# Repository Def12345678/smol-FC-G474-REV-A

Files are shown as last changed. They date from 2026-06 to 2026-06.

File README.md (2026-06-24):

# smol-FC

**Work in progress.** This is a Betaflight-based flight controller project, currently in the hardware design phase. 
Everything can change, it's not a final product. 

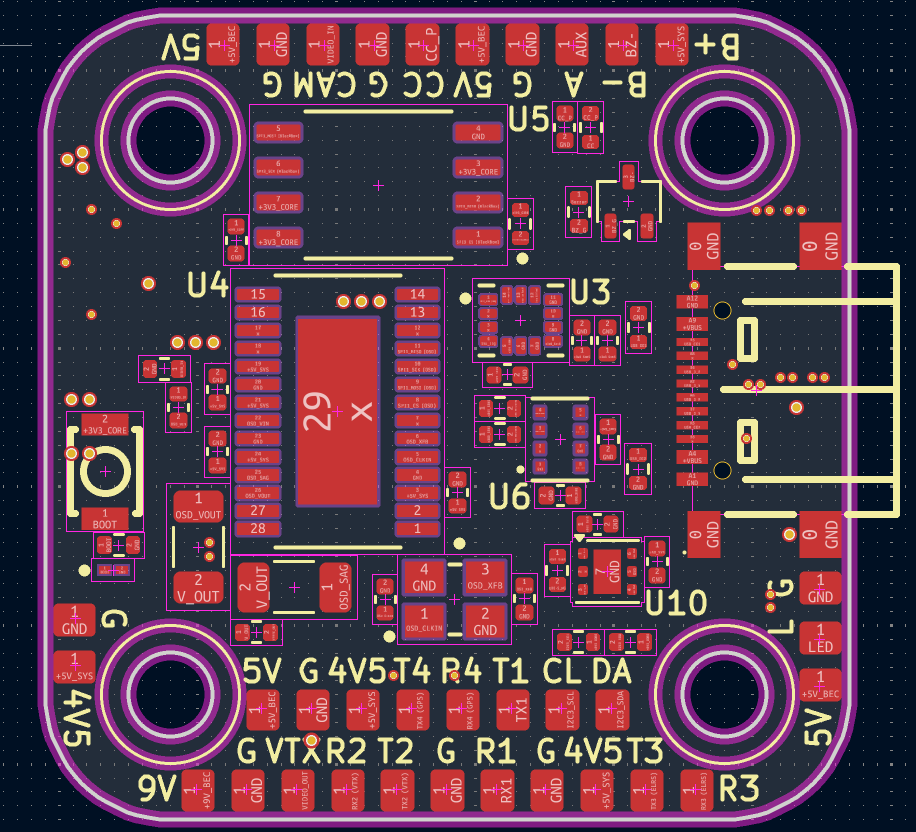
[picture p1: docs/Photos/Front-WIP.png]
Front


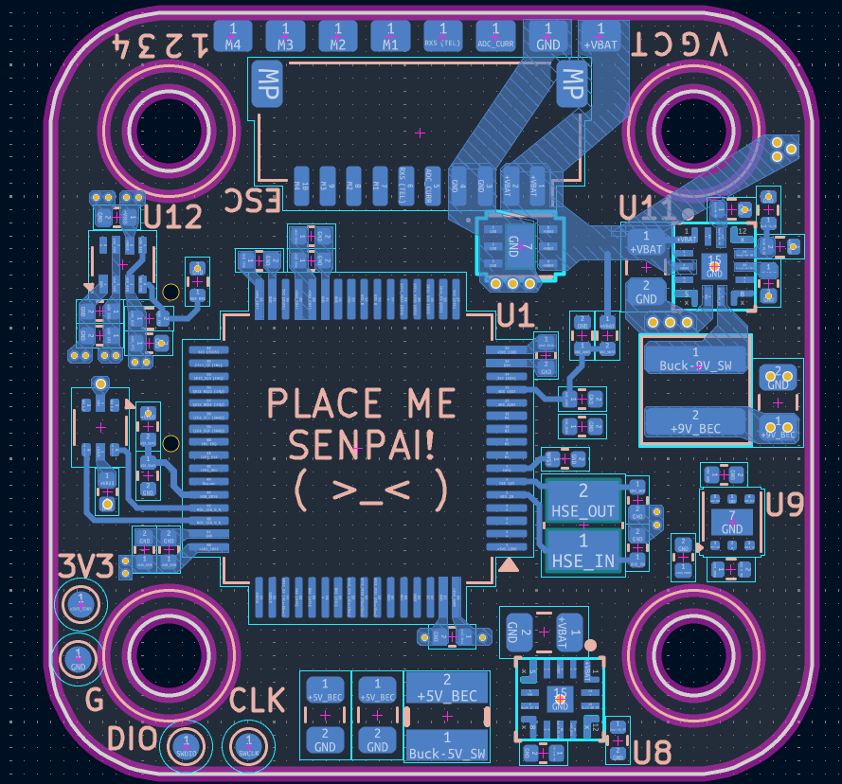
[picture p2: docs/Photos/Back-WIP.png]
Back


## License
This project is licensed under the **CERN Open Hardware Licence v2 - Weakly Reciprocal (CERN-OHL-W-v2)**.

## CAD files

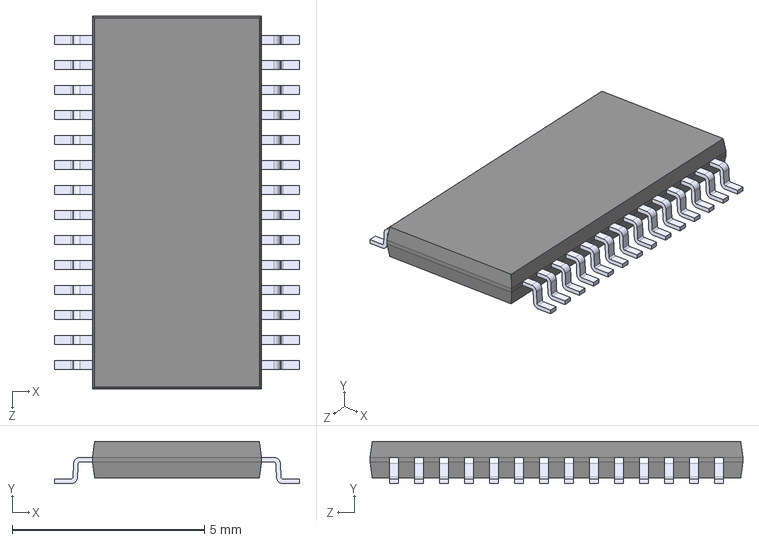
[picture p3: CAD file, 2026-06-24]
smol-FC-G474-REV-A/footprints&symbols/AT7456E/MAX7456EUI_.step
6.38 x 1.10 x 9.70 mm

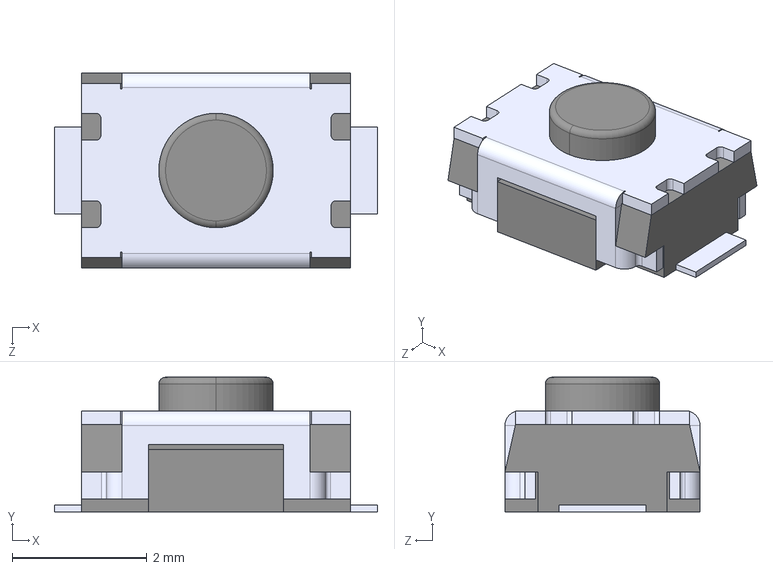
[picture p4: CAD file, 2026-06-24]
smol-FC-G474-REV-A/footprints&symbols/B3U-1000P/B3U-1000P.step
4.80 x 2.00 x 2.90 mm

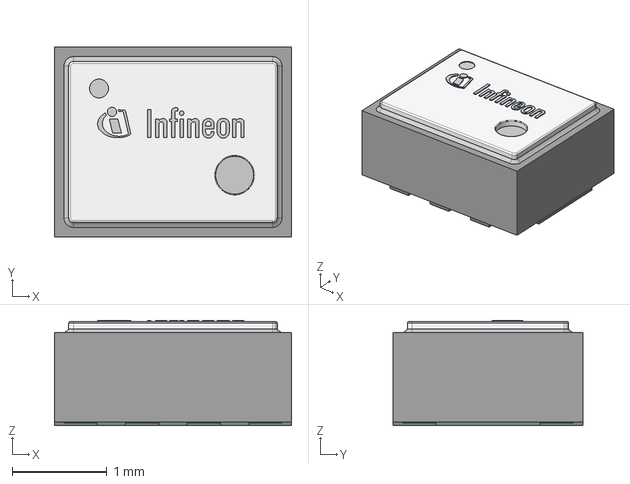
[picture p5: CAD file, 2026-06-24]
smol-FC-G474-REV-A/footprints&symbols/DPS368XTSA1/PG-VLGA-8-2_Z8B00187549_V01_3D.stp
2.50 x 2.00 x 1.11 mm

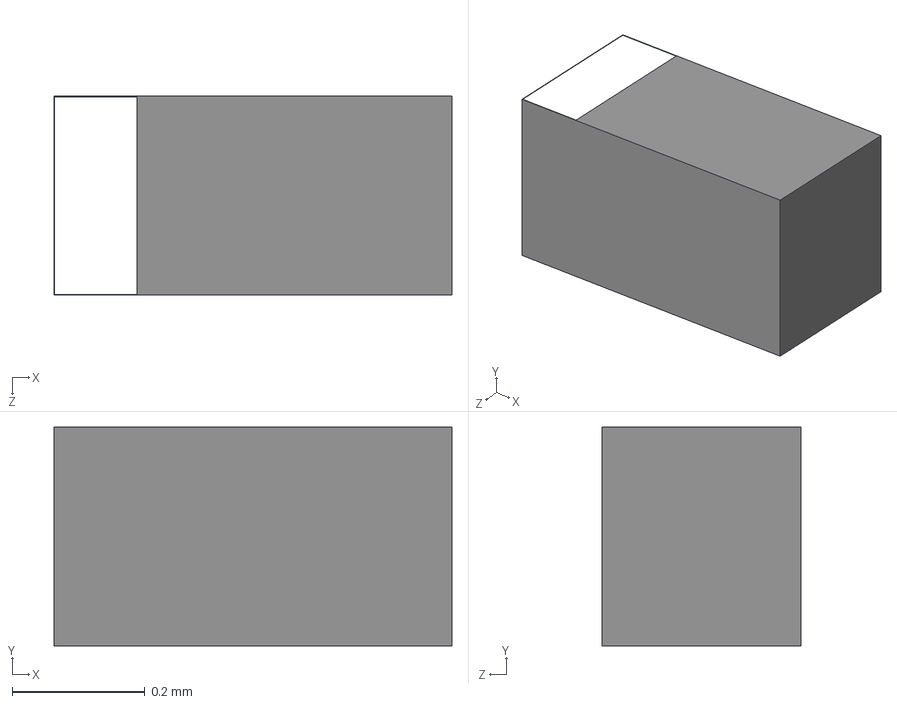
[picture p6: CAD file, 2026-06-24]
smol-FC-G474-REV-A/footprints&symbols/ESDALC6V1-1U2/ESDALC6V1-1U2.step
0.6 x 0.33 x 0.3 mm

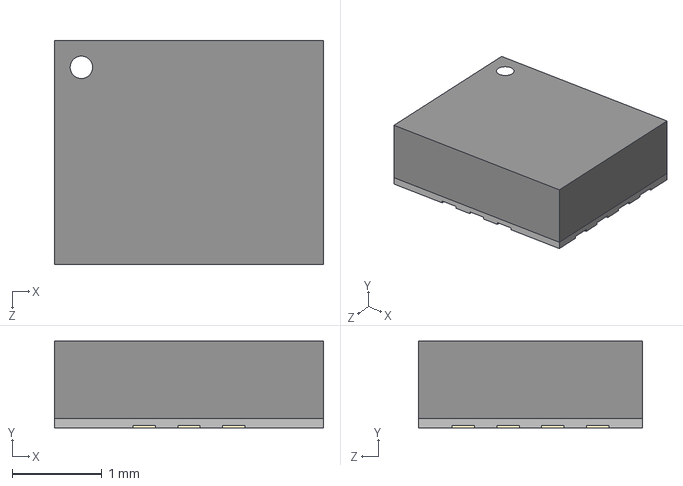
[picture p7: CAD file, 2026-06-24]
smol-FC-G474-REV-A/footprints&symbols/ICM-42688-P/ICM-42688-P.step
3.00 x 0.97 x 2.50 mm

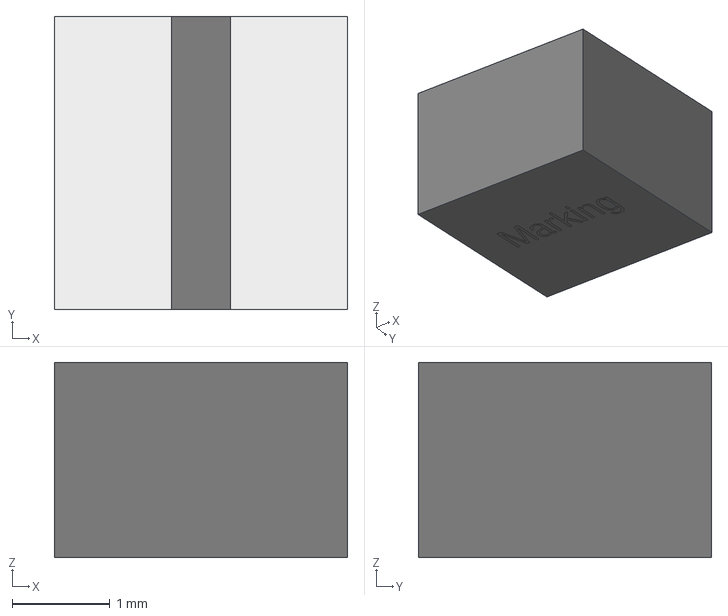
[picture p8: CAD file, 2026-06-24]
smol-FC-G474-REV-A/footprints&symbols/inductor/WE-MAPI_3020+%28rev1%29.stp
3.00 x 3.00 x 2.00 mm

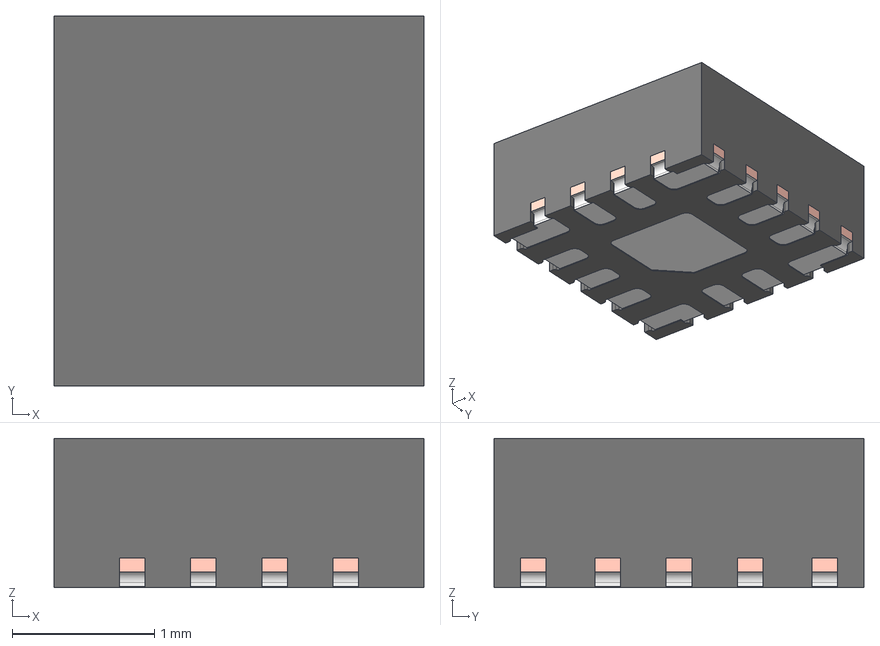
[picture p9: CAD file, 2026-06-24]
smol-FC-G474-REV-A/footprints&symbols/LMQ66430/RXB0014A.stp
2.60 x 2.60 x 1.05 mm
FRAME
PIN1_AREA

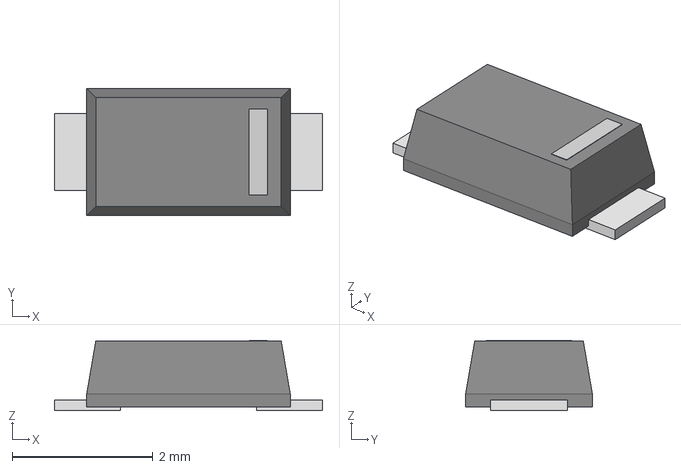
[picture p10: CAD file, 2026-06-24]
smol-FC-G474-REV-A/footprints&symbols/MBR230LSFT1G/CR_0LSFT1G_ONS.step
3.81 x 1.80 x 0.997 mm

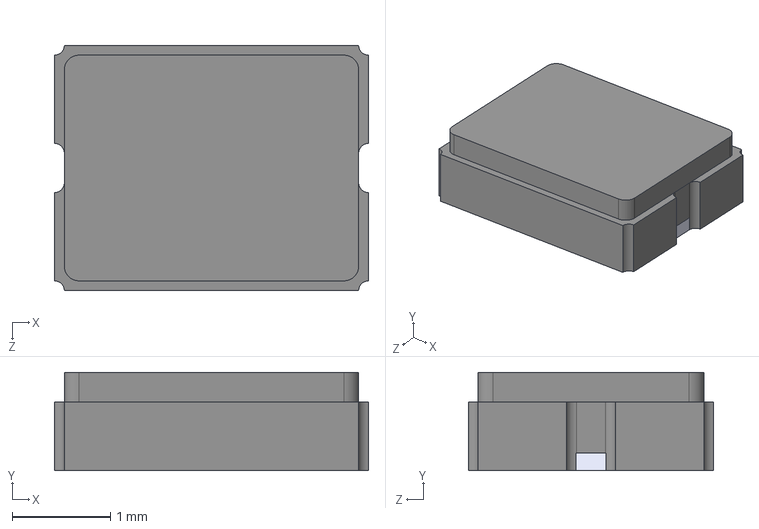
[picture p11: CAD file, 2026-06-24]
smol-FC-G474-REV-A/footprints&symbols/NX3225GD/NX3225GD-8MHZ-STD-CRA-3.step
3.20 x 1.00 x 2.50 mm

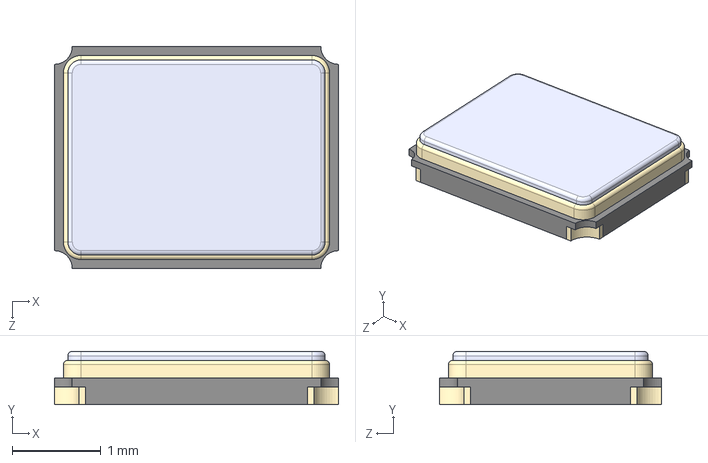
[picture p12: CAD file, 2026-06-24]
smol-FC-G474-REV-A/footprints&symbols/SX1B27.000F0810F30/TSX-3225_16.0000MF18X-AC3.step
3.20 x 0.6 x 2.50 mm

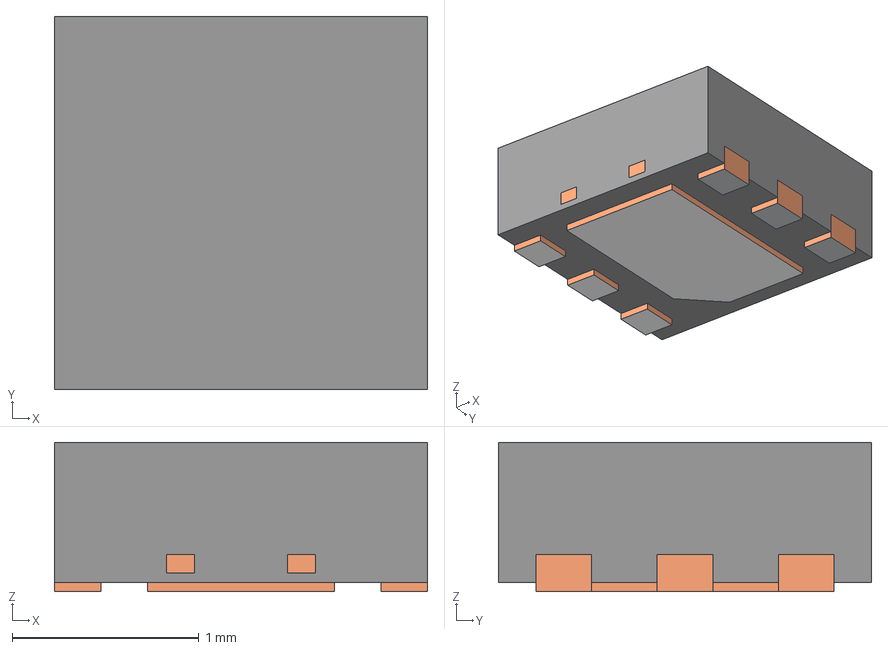
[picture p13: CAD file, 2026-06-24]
smol-FC-G474-REV-A/footprints&symbols/TVS3300DRVR/DRV0006A.stp
2.00 x 2.00 x 0.8 mm
BODY-SON
FRAME-DRV0006A
PIN1-ID

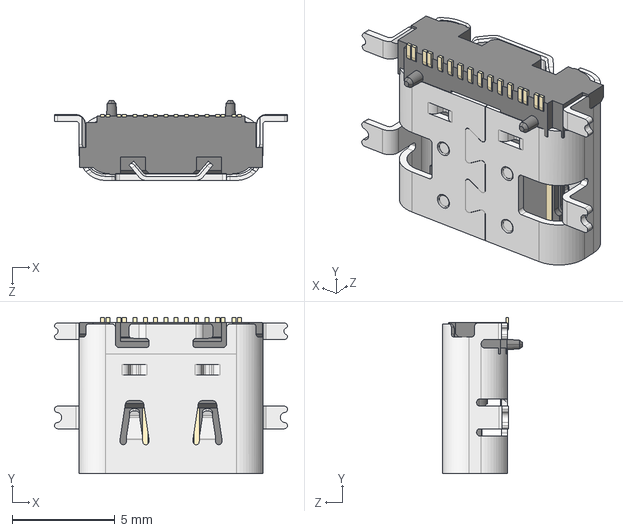
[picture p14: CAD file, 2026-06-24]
smol-FC-G474-REV-A/footprints&symbols/USB-C-SMD/USB-TYPE-C-SMD_TYPE-C-16P-QTWT.step
11.3 x 7.60 x 3.89 mm

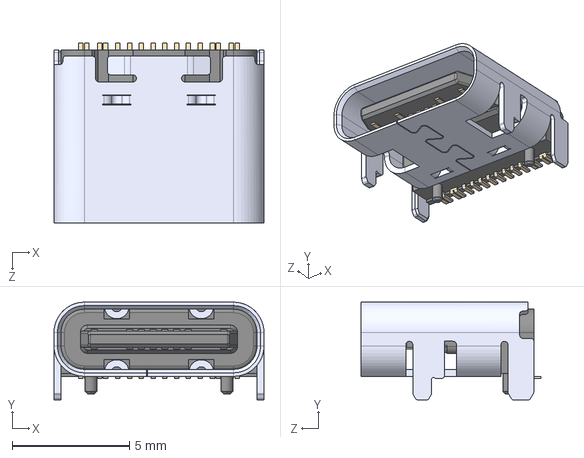
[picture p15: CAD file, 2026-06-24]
smol-FC-G474-REV-A/footprints&symbols/USB-C/TYPE-C_16PIN_2MD__073_.step
8.94 x 4.16 x 7.65 mm

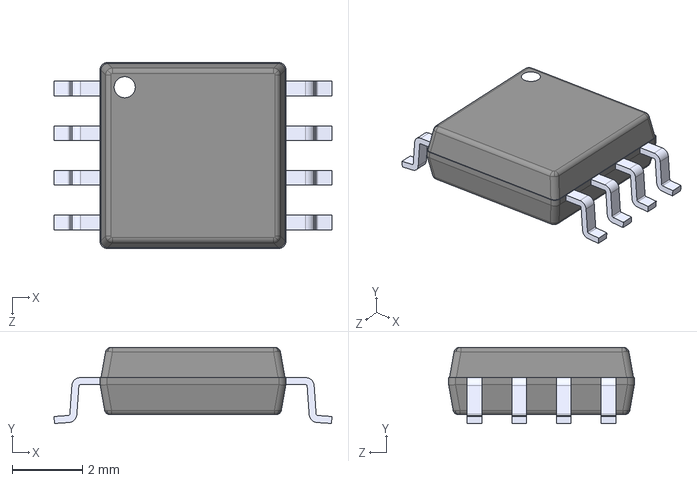
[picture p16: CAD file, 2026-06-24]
smol-FC-G474-REV-A/footprints&symbols/W25Q128JVSIQ/W25Q128JVSIQ.step
7.90 x 2.16 x 5.28 mm

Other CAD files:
freecad/smol-FC-G474-REV-A.FCStd
smol-FC-G474-REV-A/footprints&symbols/B3U-1000P/KEY-SMD_2P-L3.0-W2.5-H1.6-LS4.0.step
smol-FC-G474-REV-A/footprints&symbols/inductor/XAL4030-682MEC--3DModel-STEP-56544.STEP

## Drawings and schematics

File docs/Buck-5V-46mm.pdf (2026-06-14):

## WEBENCH ® Design Report

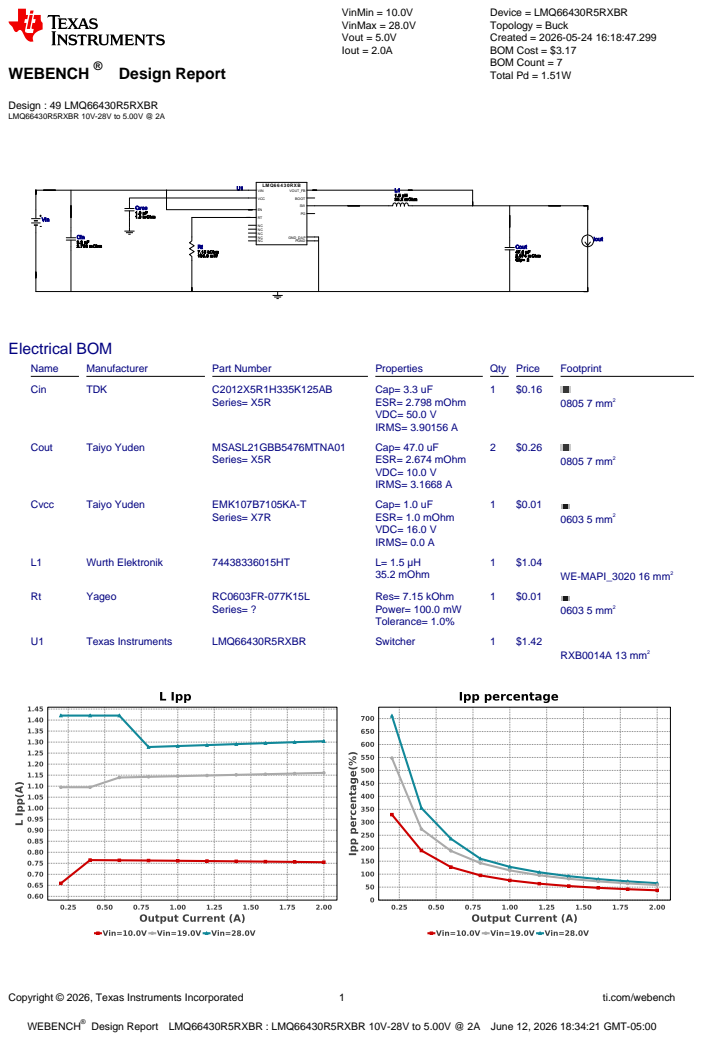
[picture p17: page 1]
Copyright © 2026, Texas Instruments Incorporated; ti.com/webench; WEBENCH®; Design : 49 LMQ66430R5RXBR LMQ66430R5RXBR 10V-28V to 5.00V @ 2A; VinMin = 10.0V VinMax = 28.0V Vout = 5.0V Iout = 2.0A; Device = LMQ66430R5RXBR Topology = Buck Created = 2026-05-24 16:18:47.299 BOM Cost = $3.17 BOM Count = 7 Total Pd = 1.51W; LM Q6 6 4 3 0 RXB; VIN; PGND; BOOT; VCC; VOUT_FB; GND_DAP; Cout 47.0 µF; 2.674 m Ohm Qty= 2; Cin 3.3 µF 2.798 m Ohm; Cvcc 1.0 µF 1.0 m Ohm; L1 1.5 µH 35.2 m Ohm; Rt 7.15 kOhm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

Design Report LMQ66430R5RXBR : LMQ66430R5RXBR 10V-28V to 5.00V @ 2A June 12, 2026 18:34:21 GMT-05:00

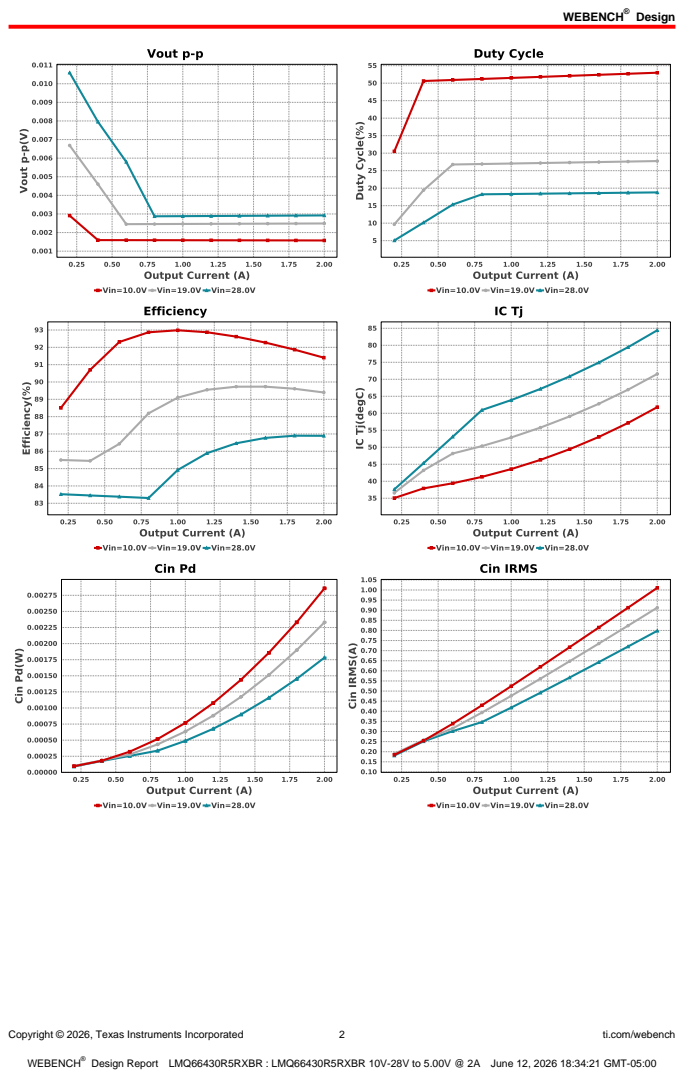
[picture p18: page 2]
Design; Copyright © 2026, Texas Instruments Incorporated; ti.com/webench

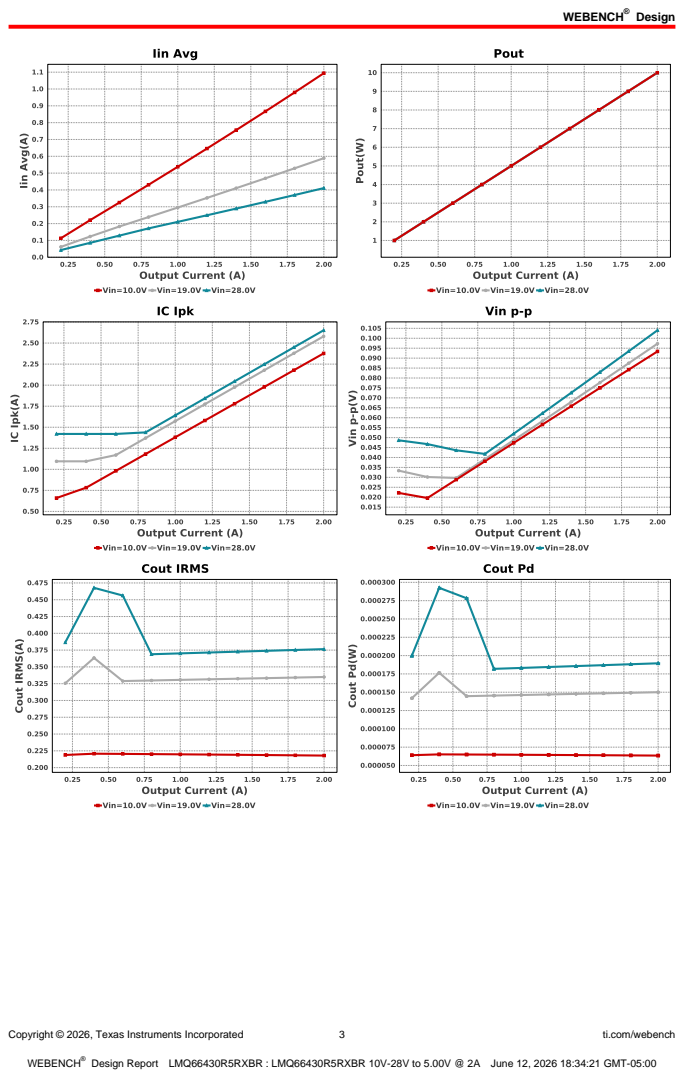
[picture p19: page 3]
Copyright © 2026, Texas Instruments Incorporated; ti.com/webench

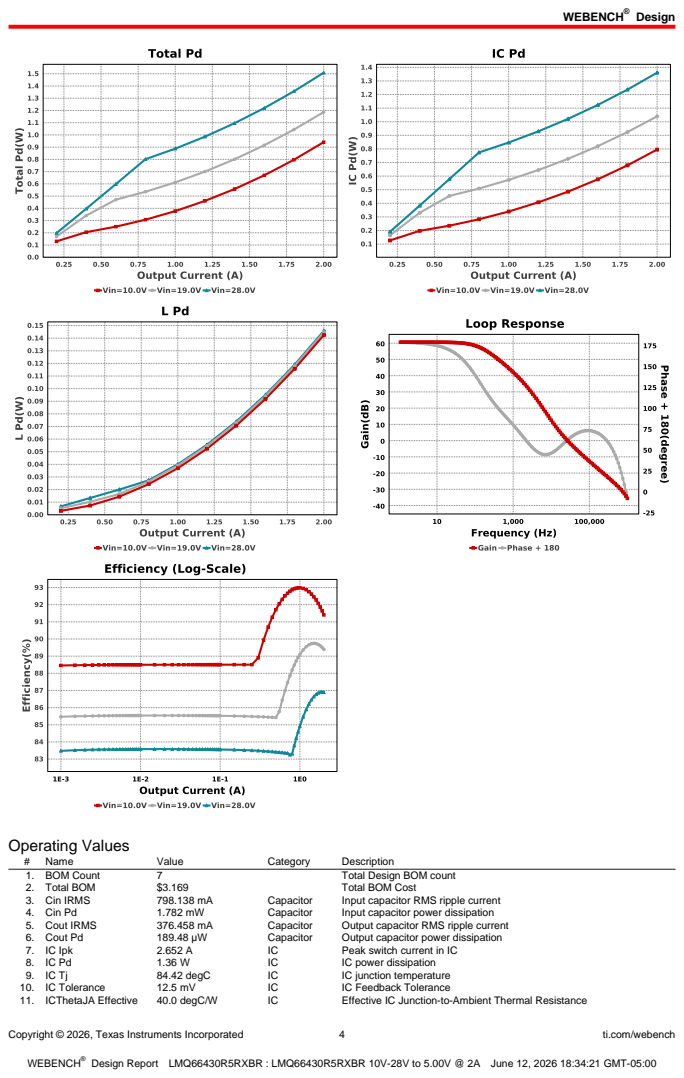
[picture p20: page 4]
Copyright © 2026, Texas Instruments Incorporated; ti.com/webench; Operating Values; Name; Value; Category; Description; 1. BOM Count; Total Design BOM count; 2. Total BOM; Total BOM Cost; 3. Cin IRMS; Capacitor; Input capacitor RMS ripple current; 4. Cin Pd; Input capacitor power dissipation; 5. Cout IRMS; Output capacitor RMS ripple current; 6. Cout Pd; Output capacitor power dissipation; 7. IC Ipk; Peak switch current in IC; IC power dissipation; 84.42 degC; IC junction temperature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

Copyright © 2026, Texas Instruments Incorporated | 5 | ti.com/webench
# | Name | Value | Category | Description

12. Iin Avg | 411.01 mA | IC | Average input current
13. Ipp percentage | 65.204 % | Inductor | Inductor ripple current percentage (with respect to average inductor
| | | | current)
14. L Ipp | 1.304 A | Inductor | Peak-to-peak inductor ripple current
15. L Pd | 145.79 mW | Inductor | Inductor power dissipation
16. Cin Pd | 1.782 mW | Power | Input capacitor power dissipation
17. Cout Pd | 189.48 µW | Power | Output capacitor power dissipation
18. IC Pd | 1.36 W | Power | IC power dissipation
19. L Pd | 145.79 mW | Power | Inductor power dissipation
20. Total Pd | 1.508 W | Power | Total Power Dissipation
21. Cross Freq | 26.776 kHz | System
| | | Information | Bode plot crossover frequency
22. Duty Cycle | 18.791 % | System
| | | Information | Duty cycle
23. Efficiency | 86.894 % | System
| | | Information | Steady state efficiency
24. FootPrint | 46.0 mm² | System
| | | Information | Total Foot Print Area of BOM components
25. Frequency | 2.176 MHz | System
| | | Information | Switching frequency
26. Gain Marg | -34.259 dB | System
| | | Information | Bode Plot Gain Margin
27. Iout | 2.0 A | System
| | | Information | Iout operating point
28. Low Freq Gain | 60.627 dB | System
| | | Information | Gain at 1Hz
29. Mode | CCM | System
| | | Information | Conduction Mode
30. Phase Marg | 62.489 deg | System
| | | Information | Bode Plot Phase Margin
31. Pout | 10.0 W | System
| | | Information | Total output power
32. Vin | 28.0 V | System
| | | Information | Vin operating point
33. Vin p-p | 104.026 mV | System
| | | Information | Peak-to-peak input voltage
34. Vout | 5.0 V | System
| | | Information | Operational Output Voltage
35. Vout Tolerance | 250.0 m% | System
| | | Information | Vout Tolerance based on IC Tolerance (no load) and voltage divider resistors if applicable
36. Vout p-p | 2.921 mV | System
| | | Information | Peak-to-peak output ripple voltage

## Design Inputs

Name | Value | Description
Iout | 2.0 | Maximum Output Current
VinMax | 28.0 | Maximum input voltage
VinMin | 10.0 | Minimum input voltage
Vout | 5.0 | Output Voltage
| base_pn | | LMQ66430R5RXBR | Base Product Number
source | DC | Input Source Type
Ta | 30.0 | Ambient temperature


Copyright © 2026, Texas Instruments Incorporated | 6 | ti.com/webench

## Assembly

## Component Testing

Some published data on components in datasheets such as Capacitor ESR and Inductor DC resistance is based on conservative values that will guarantee that the components always exceed the specification. For design purposes it is usually better to work with typical values. Since this data is not always available it is a good practice to measure the Capacitance and ESR values of Cin and Cout, and the inductance and DC resistance of L1 before assembly of the board. Any large discrepancies in values should be electrically simulated in WEBENCH to check for instabilities and thermally simulated in WebTHERM to make sure critical temperatures are not exceeded.
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

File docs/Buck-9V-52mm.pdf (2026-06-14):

## WEBENCH ® Design Report

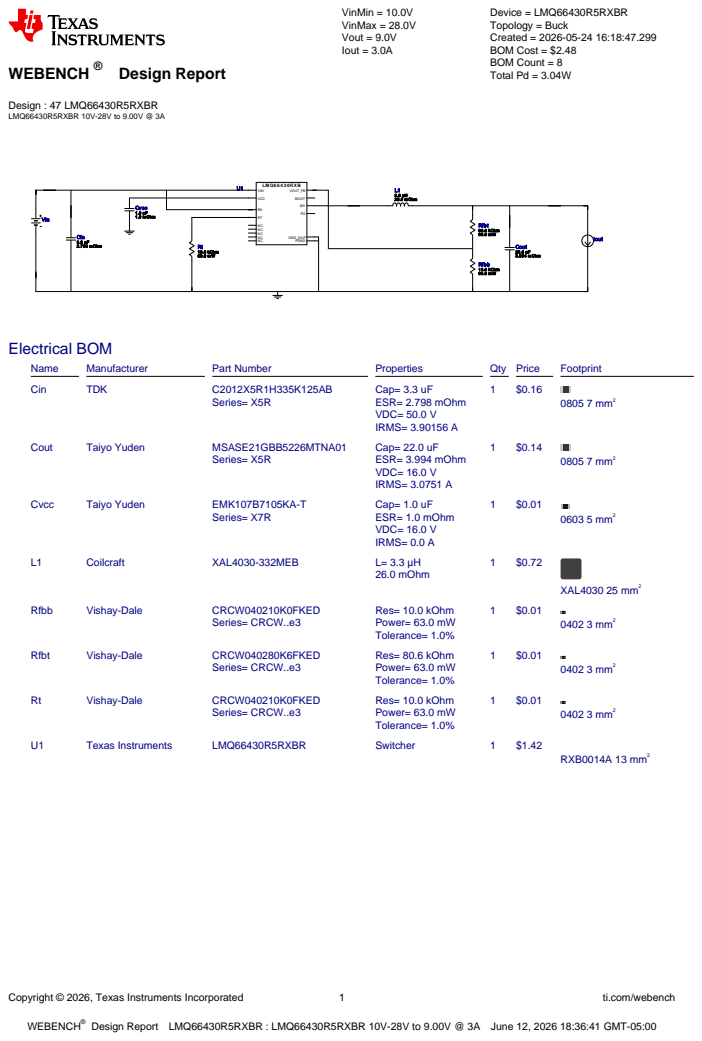
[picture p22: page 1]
Copyright © 2026, Texas Instruments Incorporated; ti.com/webench; WEBENCH®; Design : 47 LMQ66430R5RXBR LMQ66430R5RXBR 10V-28V to 9.00V @ 3A; VinMin = 10.0V VinMax = 28.0V Vout = 9.0V Iout = 3.0A; Device = LMQ66430R5RXBR Topology = Buck Created = 2026-05-24 16:18:47.299 BOM Cost = $2.48 BOM Count = 8 Total Pd = 3.04W; LM Q6 6 4 3 0 RXB; VIN; PGND; BOOT; VCC; VOUT_FB; GND_DAP; Cout 22.0 µF; 3.994 m Ohm; Cin 3.3 µF 2.798 m Ohm; Cvcc 1.0 µF 1.0 m Ohm; L1 3.3 µH 26.0 m Ohm; Rt 10.0 kOhm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

Design Report LMQ66430R5RXBR : LMQ66430R5RXBR 10V-28V to 9.00V @ 3A June 12, 2026 18:36:41 GMT-05:00

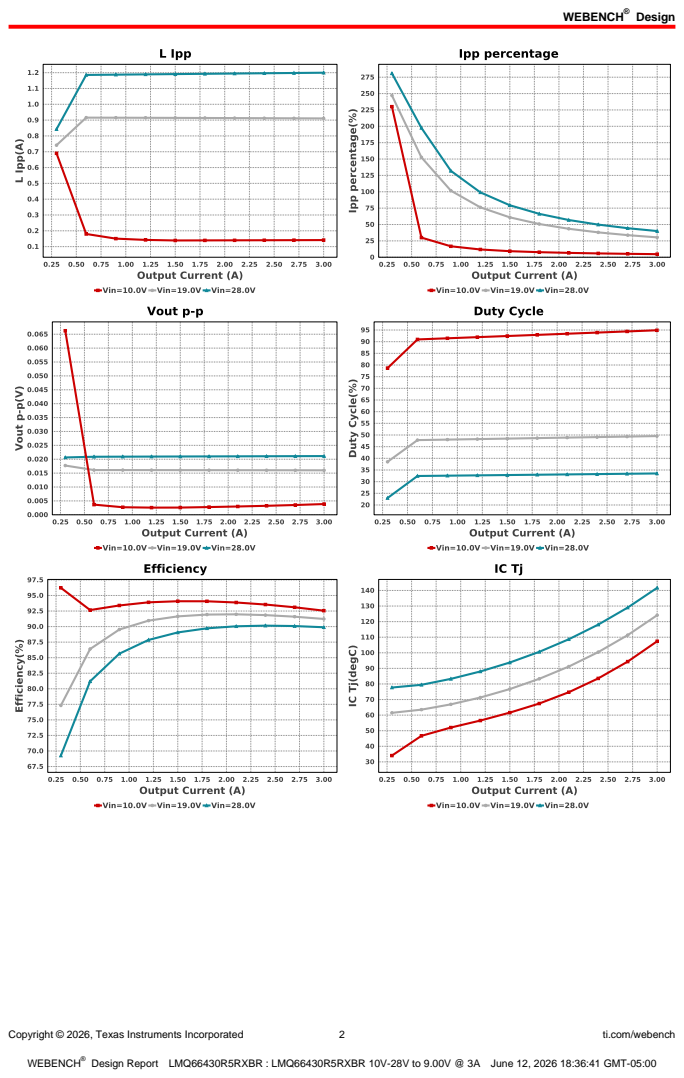
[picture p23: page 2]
Design; Copyright © 2026, Texas Instruments Incorporated; ti.com/webench

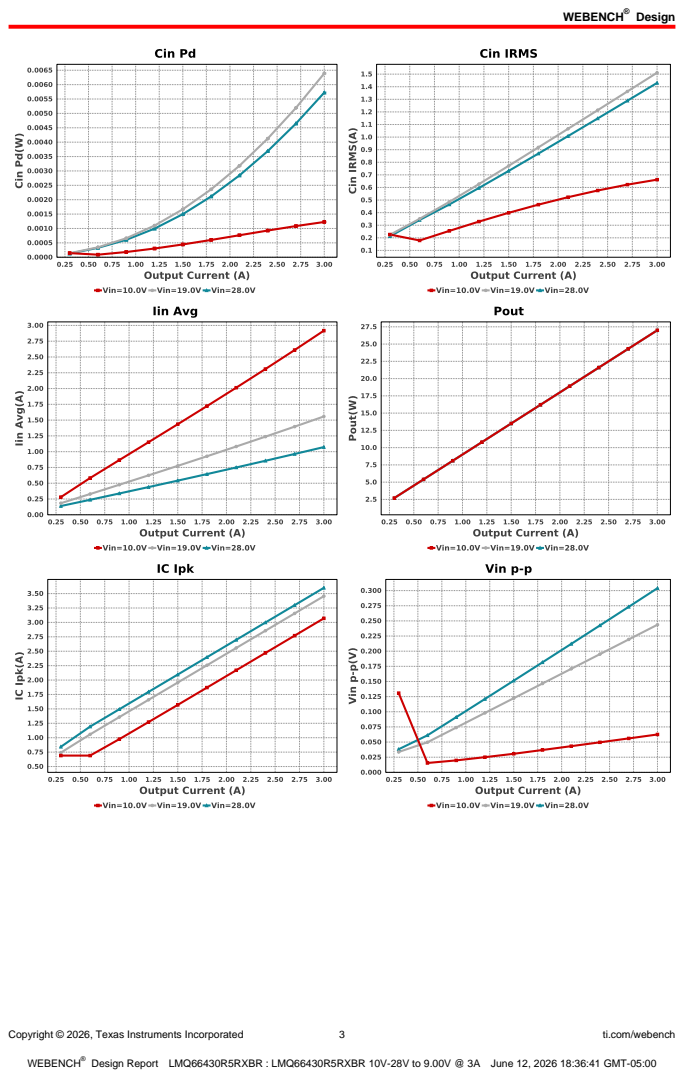
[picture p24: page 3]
Copyright © 2026, Texas Instruments Incorporated; ti.com/webench

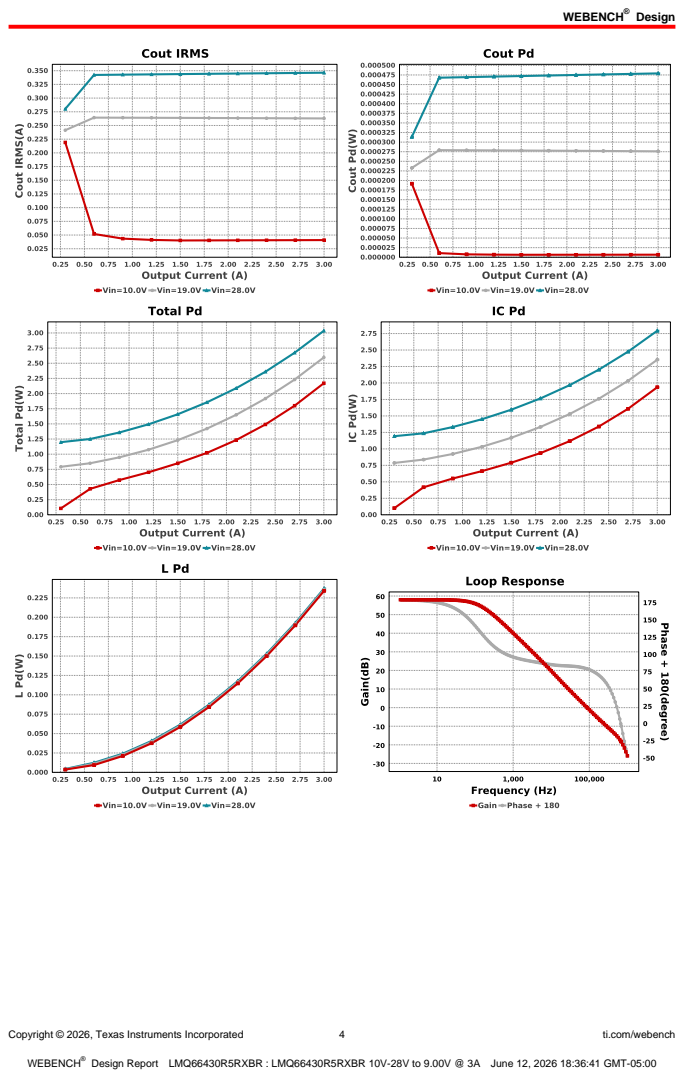
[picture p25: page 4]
Copyright © 2026, Texas Instruments Incorporated; ti.com/webench

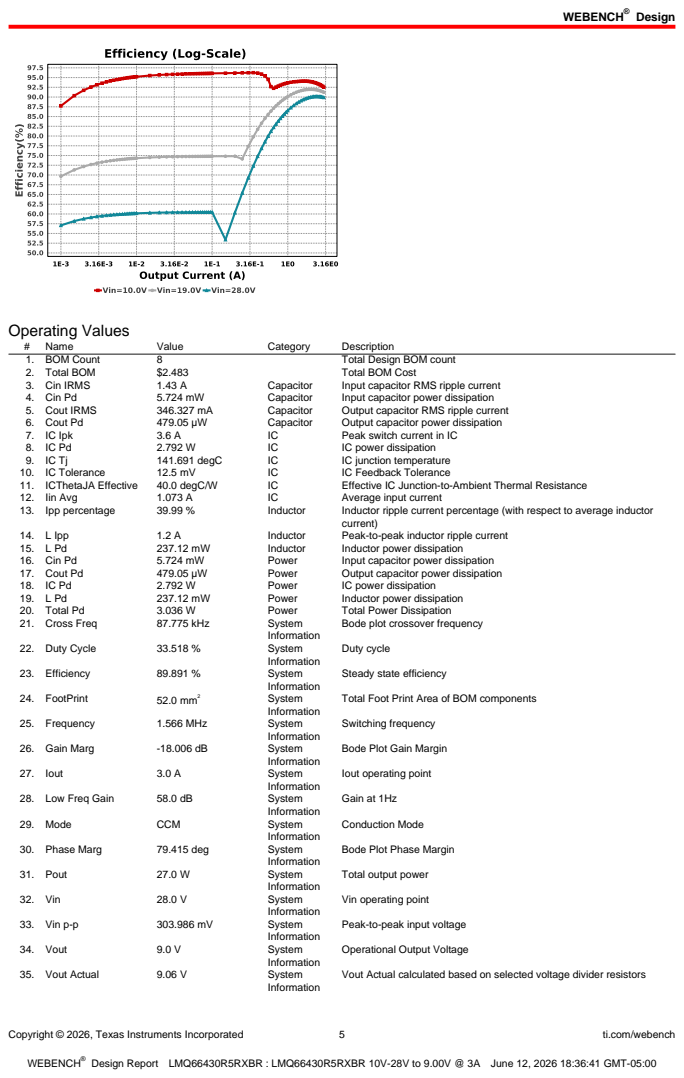
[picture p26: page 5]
Copyright © 2026, Texas Instruments Incorporated; ti.com/webench; Operating Values; Name; Value; Category; Description; 1. BOM Count; Total Design BOM count; 2. Total BOM; Total BOM Cost; 3. Cin IRMS; Capacitor; Input capacitor RMS ripple current; 4. Cin Pd; Input capacitor power dissipation; 5. Cout IRMS; Output capacitor RMS ripple current; 6. Cout Pd; Output capacitor power dissipation; 7. IC Ipk; Peak switch current in IC; IC power dissipation; 141.691 degC; IC junction temperature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

Bode plot crossover frequency

Steady state efficiency

Total Foot Print Area of BOM components

Bode Plot Gain Margin

Iout operating point

Bode Plot Phase Margin

Total output power

Vin operating point

Peak-to-peak input voltage

Operational Output Voltage

Vout Actual calculated based on selected voltage divider resistors

Copyright © 2026, Texas Instruments Incorporated | 6 | ti.com/webench
# | Name | Value | Category | Description

36. Vout Tolerance | 3.07 % | System
| | | Information | Vout Tolerance based on IC Tolerance (no load) and voltage divider resistors if applicable
37. Vout p-p | 21.137 mV | System
| | | Information | Peak-to-peak output ripple voltage

## Design Inputs

Name | Value | Description
Iout | 3.0 | Maximum Output Current
VinMax | 28.0 | Maximum input voltage
VinMin | 10.0 | Minimum input voltage
Vout | 9.0 | Output Voltage
| base_pn | | LMQ66430R5RXBR | Base Product Number
source | DC | Input Source Type
Ta | 30.0 | Ambient temperature


Copyright © 2026, Texas Instruments Incorporated | 7 | ti.com/webench

## Assembly

## Component Testing

Some published data on components in datasheets such as Capacitor ESR and Inductor DC resistance is based on conservative values that will guarantee that the components always exceed the specification. For design purposes it is usually better to work with typical values. Since this data is not always available it is a good practice to measure the Capacitance and ESR values of Cin and Cout, and the inductance and DC resistance of L1 before assembly of the board. Any large discrepancies in values should be electrically simulated in WEBENCH to check for instabilities and thermally simulated in WebTHERM to make sure critical temperatures are not exceeded.

## Soldering Component to Board

If board assembly is done in house it is best to tack down one terminal of a component on the board then solder the other terminal. For surface mount parts with large tabs, such as the DPAK, the tab on the back of the package should be pre-tinned with solder, then tacked into place by one of the pins. To solder the tab town to the board place the iron down on the board while resting against the tab, heating both surfaces simultaneously. Apply light pressure to the top of the plastic case until the solder flows around the part and the part is flush with the PCB. If the solder is not flowing around the board you may need a higher wattage iron (generally 25W to 30W is enough).
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

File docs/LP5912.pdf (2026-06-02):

## WEBENCH ® Design Report

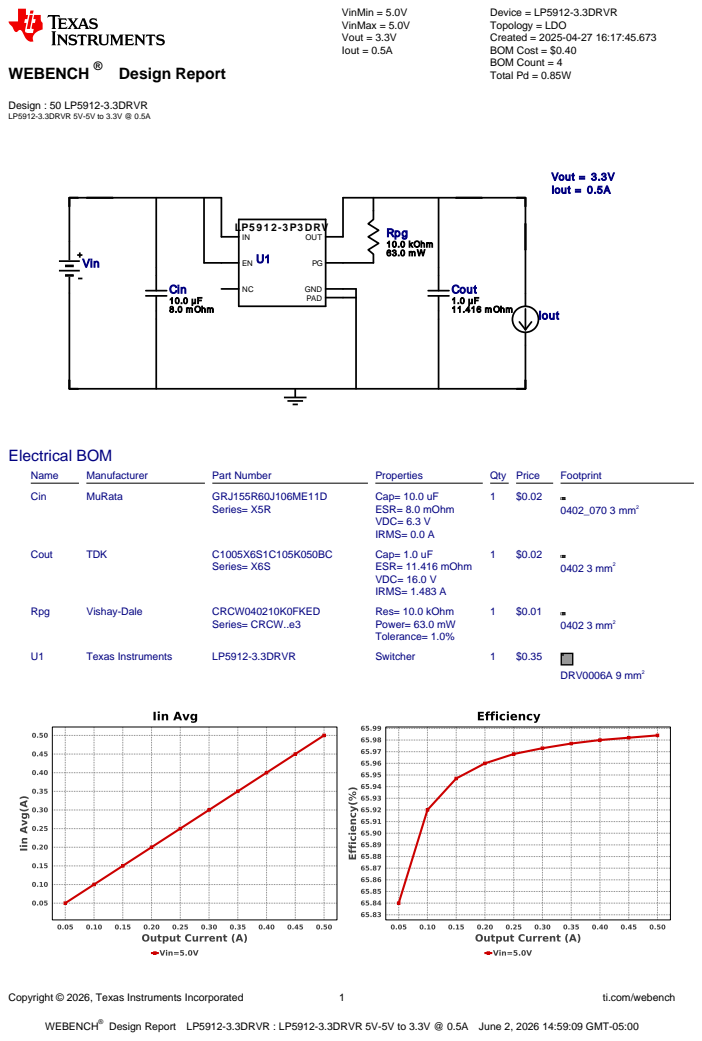
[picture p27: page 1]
Copyright © 2026, Texas Instruments Incorporated; ti.com/webench; WEBENCH®; Design : 50 LP5912-3.3DRVR LP5912-3.3DRVR 5V-5V to 3.3V @ 0.5A; VinMin = 5.0V VinMax = 5.0V Vout = 3.3V Iout = 0.5A; Device = LP5912-3.3DRVR Topology = LDO Created = 2025-04-27 16:17:45.673 BOM Cost = $0.40 BOM Count = 4 Total Pd = 0.85W; Cin 10.0 µF 8.0 m Ohm; Cout 1.0 µF 11.416 m Ohm; Rpg 10.0 kOhm 63.0 m W; LP5 9 1 2 -3 P3 DRV OUT; GND; PAD; Vout = 3.3V Iout = 0.5A; Vin; Iout; Electrical BOM; Name; Manufacturer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

Design Report LP5912-3.3DRVR : LP5912-3.3DRVR 5V-5V to 3.3V @ 0.5A June 2, 2026 14:59:09 GMT-05:00

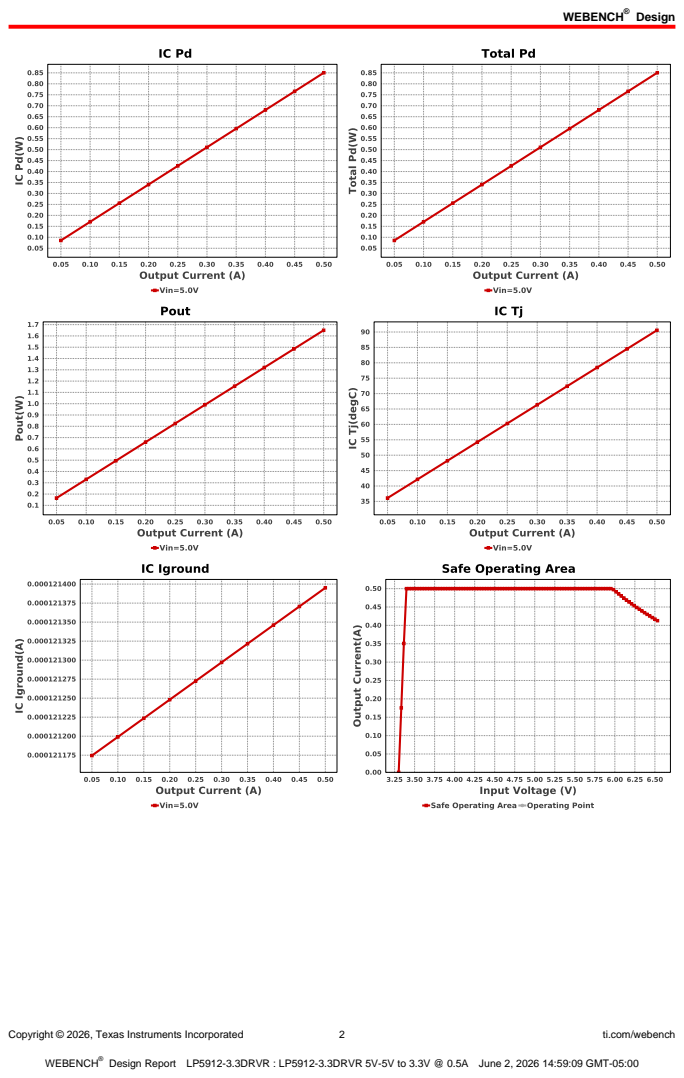
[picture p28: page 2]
Design; Copyright © 2026, Texas Instruments Incorporated; ti.com/webench

Copyright © 2026, Texas Instruments Incorporated; ti.com/webench; Operating Values; Name; Value; Category; Description; 1. BOM Count; Total Design BOM count; 2. Total BOM; Total BOM Cost; 3. IC Iground; IC ground current; IC power dissipation; 90.563 degC; IC junction temperature; 6. IC Tolerance; IC Feedback Tolerance; 7. ICThetaJA; 71.2 degC/W; IC junction-to-ambient thermal resistance; 8. Iin Avg; Average input current; 9. IOUT_OP; Op Point; Iout operating point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

Steady state efficiency

Total Foot Print Area of BOM components

Total output power

Input Source ripple voltage

Operational Output Voltage

Vout Tolerance based on IC Tolerance (no load) and voltage divider
resistors if applicable
Peak-to-peak output ripple voltage


Copyright © 2026, Texas Instruments Incorporated | 4 | ti.com/webench

## Assembly

## Component Testing

Some published data on components in datasheets such as Capacitor ESR and Inductor DC resistance is based on conservative values that will guarantee that the components always exceed the specification. For design purposes it is usually better to work with typical values. Since this data is not always available it is a good practice to measure the Capacitance and ESR values of Cin and Cout, and the inductance and DC resistance of L1 before assembly of the board. Any large discrepancies in values should be electrically simulated in WEBENCH to check for instabilities and thermally simulated in WebTHERM to make sure critical temperatures are not exceeded.

## Soldering Component to Board

If board assembly is done in house it is best to tack down one terminal of a component on the board then solder the other terminal. For surface mount parts with large tabs, such as the DPAK, the tab on the back of the package should be pre-tinned with solder, then tacked into place by one of the pins. To solder the tab town to the board place the iron down on the board while resting against the tab, heating both surfaces simultaneously. Apply light pressure to the top of the plastic case until the solder flows around the part and the part is flush with the PCB. If the solder is not flowing around the board you may need a higher wattage iron (generally 25W to 30W is enough).

## Initial Startup of Circuit

It is best to initially power up the board by setting the input supply voltage to the lowest operating input voltage 5.0V and set the input supply's current limit to zero. With the input supply off connect up the input supply to Vin and GND. Connect a digital volt meter and a load if needed to set the minimum Iout of the design from Vout and GND. Turn on the input supply and slowly turn up the current limit on the input supply. If the voltage starts to rise on the input supply continue increasing the input supply current limit while watching the output voltage. If the current increases on the input supply, but the voltage remains near zero, then there may be a short or a component misplaced on the board. Power down the board and visually inspect for solder bridges and recheck the diode and capacitor polarities. Once the power supply circuit is operational then more extensive testing may include full load testing, transient load and line tests to compare with simulation results.
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

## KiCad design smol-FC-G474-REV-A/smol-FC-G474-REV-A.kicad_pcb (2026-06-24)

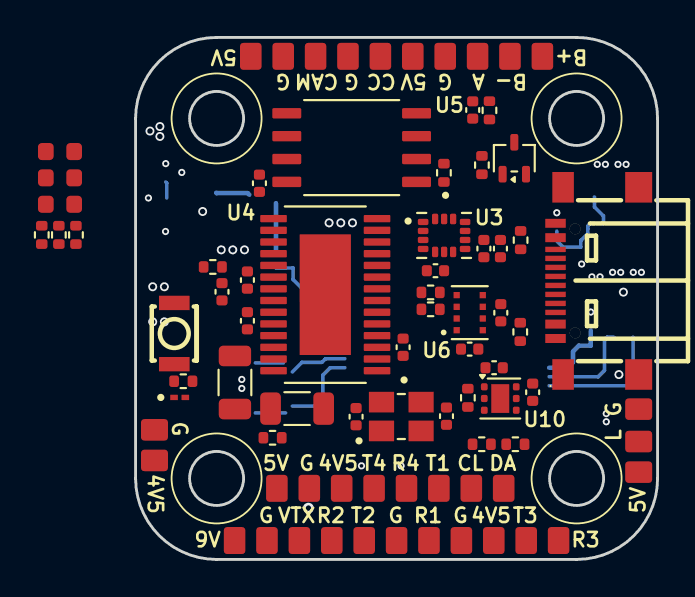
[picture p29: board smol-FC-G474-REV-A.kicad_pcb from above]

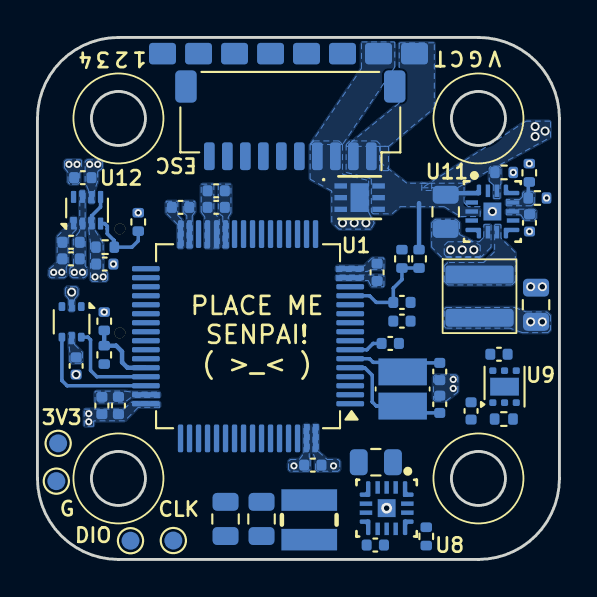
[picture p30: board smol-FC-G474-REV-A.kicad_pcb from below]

Board: 6 copper layers, 29.0 x 29.0 mm, 140 parts (60 on the bottom side), 83 nets.

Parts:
3V3: TestPoint; TestPoint_Pad_D1.0mm
4V5, 4V5#2, 4V5#3, 5V, 5V#2, 5V#3, 5V#4, 9V: TestPoint; pad-1.2x1.5
A: TestPoint; pad-1.2x1.5
B+: TestPoint; pad-1.2x1.5
B-: TestPoint; pad-1.2x1.5
C1, C2, C3, C4, C7, C8, C9, C10, C11, C14, C15, C16, C18, C20, C25, C26, C27: 100n; C_0402_1005Metric
C5, C28: 4.7u; C_0402_1005Metric
C6, C33, C34, C36, C39: 1u; C_0402_1005Metric
C12, C13, C23, C24: 10p; C_0402_1005Metric
C17: 2.2u; C_0402_1005Metric
C19: 10n; C_0402_1005Metric
C21, C22: 47u; C_1206_3216Metric
C29, C37: 3.3u; C_0805_2012Metric
C30, C31: 47u; C_0805_2012Metric
C32, C35, C40, C41, C42, C43: 10u; C_0402_1005Metric
C38: 22u; C_0805_2012Metric
CAM: TestPoint; pad-1.2x1.5
CC: TestPoint; pad-1.2x1.5
CL: TestPoint; pad-1.2x1.5
CLK: TestPoint; TestPoint_Pad_D1.0mm
CURR1: TestPoint; pad-1.2x1.5
D1, D2: LED; LED_0603_1608Metric
D3: ESD; DIODE_ESDALC6V1-1U2
D4: RED; LED_0603_1608Metric
DA: TestPoint; pad-1.2x1.5
DIO: TestPoint; TestPoint_Pad_D1.0mm
ESC: ESC; JST_SH_SM10B-SRSS-TB_1x10-1MP_P1.00mm_Horizontal
G: TestPoint; pad-1.2x1.5
G#2, G#3, G#4, G#5, G#6, G#7, G#8, G#9: TestPoint; pad-1.2x1.5
G#10: TestPoint; TestPoint_Pad_D1.0mm
GND4: TestPoint; pad-1.2x1.5
L: TestPoint; pad-1.2x1.5
L1: 1.5u; IND-SMD_L3.0-W3.0_YSMC0320H
L2: 3.3u; APH0430C-3R3M-TCD5
M1, M2, M3, M4: TestPoint; pad-1.2x1.5
Q1: BC817W; SOT-323_SC-70
R1, R2, R8, R19: 1k; R_0402_1005Metric
R1#2, R2#2, R3, R4: TestPoint; pad-1.2x1.5
R3#2, R6, R7, R25: 100k; R_0402_1005Metric
R4#2, R5, R20, R22, R24, R26: 10k; R_0402_1005Metric
R9, R10: 5.1k; R_0402_1005Metric
R11, R12: 75; R_0402_1005Metric
R13: 10K; R_0402_1005Metric
R14, R15, R17, R18: 4.7k; R_0402_1005Metric
R16: 330; R_0402_1005Metric
R21: 7.15k; R_0402_1005Metric
R23: 80.6k; R_0402_1005Metric
R27: 39k; R_0402_1005Metric
SW1: BOOT; KEY-SMD_B3U-1000PM
T1, T2, T3, T4: TestPoint; pad-1.2x1.5
TEL1: TestPoint; pad-1.2x1.5
U1: STM32G474RETx; LQFP-64_10x10mm_P0.5mm
U2: USBLC6-2P6; SOT-666
U3: ICM-42688-P; PQFN50P300X250X97-14N
U4: AT7456E; SOP65P637X110-28N
U5: W25Q128JVSIQ; SOIC127P790X216-8N
U6: DPS368XTSA1; XDCR_DPS368XTSA1
U7: TVS3300DRVR; DRV6_1X1P6_TEX
U8, U11: LMQ66430R5RXBR; RXB0014A-MFG
U9, U10: LP5912-3.3DRV; WSON-6-1EP_2x2mm_P0.65mm_EP1x1.6mm
U12: TPS2116DRL; SOT-583-8
USB1: TYPE-C 16P QTWT; USB-TYPE-C-SMD_TYPE-C-16P-QTWT
VBAT1: TestPoint; pad-1.2x1.5
VTX: TestPoint; pad-1.2x1.5
Y1: 8MHz; XTAL_NX3225GD-8MHZ-STD-CRA-3
Y2: 27MHz; XTAL_TSX-3225_16.0000MF18X-AC3

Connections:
+3V3_CORE: 3V3.1 (1_1), C1.1, C2.1, C3.1, C4.1, C5.1, C6.1, C7.1, C25.1, C33.1, R1.1, R2.1, R8.1, R13.1, R17.1, R18.1, R20.1, SW1.2, U1.1 (VBAT), U1.16 (VDD), U1.28 (VREF+), U1.29 (VDDA), U1.32 (VDD), U1.48 (VDD), U1.64 (VDD), U5.3 (/WP(IO2)), U5.7 (/HOLD/RESET(IO3)), U5.8 (VCC), U9.1 (OUT)
+3V3_SENS: C17.1, C18.1, C19.1, C26.1, C27.1, C36.1, R14.1, R15.1, R22.1, U3.5 (VDDIO), U3.8 (VDD), U6.6 (VDDIO), U6.8 (VDD), U10.1 (OUT)
+5V_BEC: 5V.1 (1_1), 5V#2.1 (1_1), 5V#3.1 (1_1), 5V#4.1 (1_1), C30.1, C31.1, C42.1, L1.2, R25.1, U8.11 (VOUT_FB), U12.3 (VIN1), U12.5 (MODE)
+5V_SYS: 4V5.1 (1_1), 4V5#2.1 (1_1), 4V5#3.1 (1_1), B+.1 (1_1), C14.1, C15.1, C16.1, C32.1, C35.1, C40.1, C41.1, U4.3 (DVDD), U4.19 (~RESET), U4.21 (AVDD), U4.24 (PVDD), U9.4 (EN), U9.6 (IN), U10.4 (EN), U10.6 (IN), U12.2 (VOUT), U12.7 (VOUT)
+9V_BEC: 9V.1 (1_1), C38.1, L2.2, R23.1
+VBAT: C29.1, C37.1, ESC.1, ESC.2, R3#2.1, U7.4 (IN), U7.5 (IN), U7.6 (IN), U8.1 (EN), U8.3 (VIN), U11.1 (EN), U11.3 (VIN), VBAT1.1 (1_1)
+VBUS: C11.1, C43.1, R6.1, U2.5 (VBUS), U12.6 (VIN2), USB1.A4 (VBUS), USB1.A9 (VBUS)
/Connectors/AUX: A.1 (1_1), U1.26 (PB2)
/Connectors/BZ-: B-.1 (1_1), Q1.3 (C)
/Connectors/BZ_G: Q1.1 (B), R19.2
/Connectors/Buzzer: R19.1, U1.43 (PA9)
/Connectors/CC: R16.1, U1.62 (PB9)
/Connectors/CC_P: C28.1, CC.1 (1_1), R16.2
/Connectors/I2C3_SCL: CL.1 (1_1), R17.2, U1.42 (PA8)
/Connectors/I2C3_SDA: DA.1 (1_1), R18.2, U1.41 (PC9)
/Connectors/LED: L.1 (1_1), U1.25 (PB1)
/Connectors/M1: ESC.7, M1.1 (1_1), U1.8 (PC0)
/Connectors/M2: ESC.8, M2.1 (1_1), U1.9 (PC1)
/Connectors/M3: ESC.9, M3.1 (1_1), U1.10 (PC2)
/Connectors/M4: ESC.10, M4.1 (1_1), U1.11 (PC3)
/Connectors/RX1: R1#2.1 (1_1), U1.60 (PB7)
/Connectors/RX2 (VTX): R2#2.1 (1_1), U1.17 (PA3)
/Connectors/RX3 (ELRS): R3.1 (1_1), U1.33 (PB11)
/Connectors/RX4 (GPS): R4.1 (1_1), U1.53 (PC11)
/Connectors/RX5 (TEL): ESC.6, TEL1.1 (1_1), U1.55 (PD2)
/Connectors/TX1: T1.1 (1_1), U1.59 (PB6)
/Connectors/TX2 (VTX): T2.1 (1_1), U1.14 (PA2)
/Connectors/TX3 (ELRS): T3.1 (1_1), U1.30 (PB10)
/Connectors/TX4 (GPS): T4.1 (1_1), U1.52 (PC10)
/Connectors/VIDEO_IN: C20.1, CAM.1 (1_1), R11.1
/Connectors/VIDEO_OUT: R12.2, VTX.1 (1_1)
/MCU/ADC_CURR: C10.1, CURR1.1 (1_1), ESC.5, U1.12 (PA0)
/MCU/ADC_VBAT: C9.1, R3#2.2, R4#2.1, U1.13 (PA1)
/MCU/BOOT: D3.1, R5.1, SW1.1, U1.61 (PB8)
/MCU/HSE_IN: C12.1, U1.5 (PF0), Y1.1
/MCU/HSE_OUT: C13.1, U1.6 (PF1), Y1.2
/MCU/I2C4_SCL (BARO): R15.2, U1.38 (PC6), U6.4 (SCK)
/MCU/I2C4_SDA (BARO): R14.2, U1.39 (PC7), U6.3 (SDI)
/MCU/IMU_IRQ: U1.40 (PC8), U3.4 (INT1/INT)
/MCU/LED_B: D1.1 (K), U1.24 (PB0)
/MCU/LED_B_R: D1.2 (A), R1.2
/MCU/LED_G: D2.1 (K), U1.23 (PC5)
/MCU/LED_G_R: D2.2 (A), R2.2
/MCU/LED_PWR: D4.2 (A), R8.2
/MCU/MCU_USB_D_N: U1.45 (PA11), U2.6 (I/O1)
/MCU/MCU_USB_D_P: U1.46 (PA12), U2.4 (I/O2)
/MCU/NRST: C8.1, U1.7 (PG10)
/MCU/SPI1_CS (OSD): U1.18 (PA4), U4.8 (~CS)
/MCU/SPI1_MISO (OSD): U1.20 (PA6), U4.11 (SDOUT)
/MCU/SPI1_MOSI (OSD): U1.21 (PA7), U4.9 (SDIN)
/MCU/SPI1_SCK (OSD): U1.19 (PA5), U4.10 (SCLK)
/MCU/SPI2_CS (IMU): U1.34 (PB12), U3.12 (AP_CS)
/MCU/SPI2_MISO (IMU): U1.36 (PB14), U3.1 (AP_SDO/AP_AD0)
/MCU/SPI2_MOSI (IMU): U1.37 (PB15), U3.14 (AP_SDA/AP_SDIO/AP_SDI)
/MCU/SPI2_SCK (IMU): U1.35 (PB13), U3.13 (AP_SCL/AP_SCLK)
/MCU/SPI3_CS (Blackbox): R13.2, U1.51 (PA15), U5.1 (/CS)
/MCU/SPI3_MISO (Blackbox): U1.57 (PB4), U5.2 (DO(IO1))
/MCU/SPI3_MOSI (Blackbox): U1.58 (PB5), U5.5 (DI(IO0))
/MCU/SPI3_SCK (Blackbox): U1.56 (PB3), U5.6 (CLK)
/MCU/SWCLK: CLK.1 (1_1), U1.50 (PA14)
/MCU/SWDIO: DIO.1 (1_1), U1.49 (PA13)
/MCU/USB_CC1: R10.1, USB1.B5 (CC2)
/MCU/USB_CC2: R9.1, USB1.A5 (CC1)
/MCU/USB_D_N: U2.1 (I/O1), USB1.A7 (DN1), USB1.B7 (DN2)
/MCU/USB_D_P: U2.3 (I/O2), USB1.A6 (DP1), USB1.B6 (DP2)
/MCU/USB_SENS: R6.2, R7.1, U1.44 (PA10)
/Power Supply/Buck-5V_RT: R21.1, U8.13 (RT)
/Power Supply/Buck-5V_SW: L1.1, U8.7 (SW)
/Power Supply/Buck-5V_VCC_INT: C34.1, U8.10 (VCC)
/Power Supply/Buck-9V_FB: R23.2, R24.1, U11.11 (VOUT_FB)
/Power Supply/Buck-9V_RT: R26.1, U11.13 (RT)
/Power Supply/Buck-9V_SW: L2.1, U11.7 (SW)
/Power Supply/Buck-9V_VCC_INT: C39.1, U11.10 (VCC)
/Power Supply/LDO-C_PG: R20.2, U9.3 (PG)
/Power Supply/LDO-S_PG: R22.2, U10.3 (PG)
/Power Supply/MUX_PR1: R25.2, R27.1, U12.4 (PR1)
/Sensors & IC's/OSD_CLKIN: C23.1, U4.5 (CLKIN), Y2.1
/Sensors & IC's/OSD_SAG: C22.1, U4.25 (SAG)
/Sensors & IC's/OSD_VIN: C20.2, U4.22 (VIN)
/Sensors & IC's/OSD_VOUT: C21.1, U4.26 (VOUT)
/Sensors & IC's/OSD_XFB: C24.1, U4.6 (XFB), Y2.3
/Sensors & IC's/V_OUT: C21.2, C22.2, R12.1
GND: C1.2, C2.2, C3.2, C4.2, C5.2, C6.2, C7.2, C8.2, C9.2, C10.2, C11.2, C12.2, C13.2, C14.2, C15.2, C16.2, C17.2, C18.2, C19.2, C23.2, C24.2, C25.2, C26.2, C27.2, C28.2, C29.2, C30.2, C31.2, C32.2, C33.2, C34.2, C35.2, C36.2, C37.2, C38.2, C39.2, C40.2, C41.2, C42.2, C43.2, D3.2, D4.1 (K), ESC.3, ESC.4, G.1 (1_1), G#2.1 (1_1), G#3.1 (1_1), G#4.1 (1_1), G#5.1 (1_1), G#6.1 (1_1), G#7.1 (1_1), G#8.1 (1_1), G#9.1 (1_1), G#10.1 (1_1), GND4.1 (1_1), Q1.2 (E), R4#2.2, R5.2, R7.2, R9.2, R10.2, R11.2, R21.2, R24.2, R26.2, R27.2, U1.15 (VSS), U1.27 (VSSA), U1.31 (VSS), U1.47 (VSS), U1.63 (VSS), U2.2 (GND), U3.6 (GND), U3.7 (RESV_7), U3.9 (INT2/FSYNC/CLKIN), U3.11 (RESV_11), U4.4 (DGND), U4.20 (AGND), U4.23 (PGND), U5.4 (GND), U6.1 (GND), U6.7 (GND), U7.1 (GND), U7.2 (GND), U7.3 (GND), U7.7 (EPAD), U8.6 (PGND), U8.15 (GND_DAP), U9.5 (GND), U9.7 (EP), U10.5 (GND), U10.7 (EP), U11.6 (PGND), U11.15 (GND_DAP), U12.1 (GND), USB1.0 (EH), USB1.A1 (GND), USB1.A12 (GND), Y2.2 (G), Y2.4 (G)

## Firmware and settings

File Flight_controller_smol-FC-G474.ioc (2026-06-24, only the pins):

Mcu.UserName=STM32G474RETx
PA0.GPIO_Label=CURR
PA0.Signal=ADC1_IN1
PA1.GPIO_Label=VBAT
PA1.Signal=ADC1_IN2
PA10.GPIO_Label=USD_DETECT
PA10.Signal=GPIO_Input
PA11.Signal=USB_DM
PA12.Signal=USB_DP
PA13.GPIO_Label=SWDIO
PA13.Signal=SYS_JTMS-SWDIO
PA14.GPIO_Label=SWCLK
PA14.Signal=SYS_JTCK-SWCLK
PA15.GPIO_Label=BLACKBOX_CS (SPI3)
PA15.Signal=SPI3_NSS
PA2.GPIO_Label=VTX_TX (UART2)
PA2.Signal=USART2_TX
PA3.GPIO_Label=VTX_RX (UART2)
PA3.Signal=USART2_RX
PA4.GPIO_Label=OSD_CS
PA4.Signal=SPI1_NSS
PA5.GPIO_Label=OSD_SCK (SPI1)
PA5.Signal=SPI1_SCK
PA6.GPIO_Label=OSD_MISO (SPI1)
PA6.Signal=SPI1_MISO
PA7.GPIO_Label=OSD_MOSI (SPI1)
PA7.Signal=SPI1_MOSI
PA8.GPIO_Label=EXTRA_SCL (I2C3)
PA8.Signal=I2C3_SCL
PA9.GPIO_Label=Buzzer
PA9.Signal=GPIO_Output
PB0.GPIO_Label=LED_BLUE
PB0.Signal=GPIO_Output
PB1.GPIO_Label=LED (TIM3_CH4)
PB1.Signal=S_TIM3_CH4
PB10.GPIO_Label=ELRS_TX (UART3)
PB10.Signal=USART3_TX
PB11.GPIO_Label=ELRS_RX (UART3)
PB11.Signal=USART3_RX
PB12.GPIO_Label=IMU_CS (SPI2)
PB12.Signal=SPI2_NSS
PB13.GPIO_Label=IMU_SCK (SPI2)
PB13.Signal=SPI2_SCK
PB14.GPIO_Label=IMU_MISO (SPI2)
PB14.Signal=SPI2_MISO
PB15.GPIO_Label=IMU_MOSI (SPI2)
PB15.Signal=SPI2_MOSI
PB2.GPIO_Label=EXTRA_AUX
PB2.Signal=GPIO_Output
PB3.GPIO_Label=BLACKBOX_SCK (SPI3)
PB3.Signal=SPI3_SCK
PB4.GPIO_Label=BLACKBOX_MISO (SPI3)
PB4.Signal=SPI3_MISO
PB5.GPIO_Label=BLACKBOX_MOSI (SPI3)
PB5.Signal=SPI3_MOSI
PB6.GPIO_Label=EXTRA_TX (UART1)
PB6.Signal=USART1_TX
PB7.GPIO_Label=EXTRA_RX (UART1)
PB7.Signal=USART1_RX
PB8-BOOT0.GPIO_Label=BOOT
PB8-BOOT0.Signal=GPIO_Input
PB9.GPIO_Label=CC (TIM4_CH4)
PB9.Signal=S_TIM4_CH4
PC0.GPIO_Label=M1 (TIM1_CH1)
PC0.Signal=S_TIM1_CH1
PC1.GPIO_Label=M2 (TIM1_CH2)
PC1.Signal=S_TIM1_CH2
PC10.GPIO_Label=GPS_TX (UART4)
PC10.Signal=UART4_TX
PC11.GPIO_Label=GPS_RX (UART4)
PC11.Signal=UART4_RX
PC12.GPIO_Label=TEL_TX (UART5)
PC12.Signal=UART5_TX
PC2.GPIO_Label=M3 (TIM1_CH3)
PC2.Signal=S_TIM1_CH3
PC3.GPIO_Label=M4 (TIM1_CH4)
PC3.Signal=S_TIM1_CH4
PC4.GPIO_Label=LED_AMBER
PC4.Signal=GPIO_Output
PC5.GPIO_Label=LED_GREEN
PC5.Signal=GPIO_Output
PC6.GPIO_Label=BARO_SCL (I2C4)
PC6.Signal=I2C4_SCL
PC7.GPIO_Label=BARO_SDA (I2C4)
PC7.Signal=I2C4_SDA
PC8.GPIO_Label=IMU_IRQ
PC8.Signal=GPIO_Input
PC9.GPIO_Label=EXTRA_SDA (I2C3)
PC9.Signal=I2C3_SDA
PD2.GPIO_Label=TEL_RX (UART5)
PD2.Signal=UART5_RX
PF0-OSC_IN.GPIO_Label=HSE_IN
PF0-OSC_IN.Signal=RCC_OSC_IN
PF1-OSC_OUT.GPIO_Label=HSE_OUT
PF1-OSC_OUT.Signal=RCC_OSC_OUT
PG10-NRST.GPIO_Label=NRST
PG10-NRST.Signal=GPIO_Input

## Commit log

2026-05-25 Added license, and started working on schematic
    [MCU.kicad_sch, smol-FC-G474-REV-A.kicad_sch]
2026-05-25 Changed license
    [MCU.kicad_sch, smol-FC-G474-REV-A.kicad_sch]
2026-05-26 added USB-C section
    [MCU.kicad_sch, TYPE-C_16PIN_2MD__073_.step]
2026-05-27 Schematic update
    [ESDALC6V1-1U2.step, MAX7456EUI_.step, MCU.kicad_sch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]
2026-05-29 Added whole new schematic (sensors, OSD, Blackbox), changed text in cubemx
    [ICM-42688-P.step, TSX-3225_16.0000MF18X-AC3.step, W25Q128JVSIQ.step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]
2026-05-31 complete connectors layout and initialize buck converter section. Added buck docs in /docs.
    [MCU.kicad_sch, connectors.kicad_sch, power_supply.kicad_sch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]
2026-06-02 Updated Buck-5V doc, added Buck 5V/10V and LDO for 3v3 on schematic
    [MCU.kicad_sch, connectors.kicad_sch, power_supply.kicad_sch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]
2026-06-02 Changed 10V buck to 9V buck
    [CR_0LSFT1G_ONS.step, MCU.kicad_sch, connectors.kicad_sch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]
2026-06-05 Attached footprints and finalized schematic.
    [B3U-1000P.step, MCU.kicad_sch, NX3225GD-8MHZ-STD-CRA-3.step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]
2026-06-09 Finalized schematic, added power mux
    [MCU.kicad_sch, connectors.kicad_sch, power_supply.kicad_sch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]
2026-06-12 In progress PCB layout
    [KEY-SMD_2P-L3.0-W2.5-H1.6-LS4.0.step, MCU.kicad_sch, PG-VLGA-8-2_Z8B00187549_V01_3D.stp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]
2026-06-14 changed size of cap on buck's
    [DRV0006A.stp, connectors.kicad_sch, power_supply.kicad_sch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]
2026-06-24 Opis Twoich zmian
    [B3U-1000P.step, CR_0LSFT1G_ONS.step, DRV0006A.stp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]

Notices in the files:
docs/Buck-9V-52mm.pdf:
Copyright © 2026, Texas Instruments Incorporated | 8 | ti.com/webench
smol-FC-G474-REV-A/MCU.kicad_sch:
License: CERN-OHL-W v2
